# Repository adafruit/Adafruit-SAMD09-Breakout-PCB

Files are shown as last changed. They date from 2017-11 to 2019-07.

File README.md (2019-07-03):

## Adafruit SAMD09 Breakout PCB

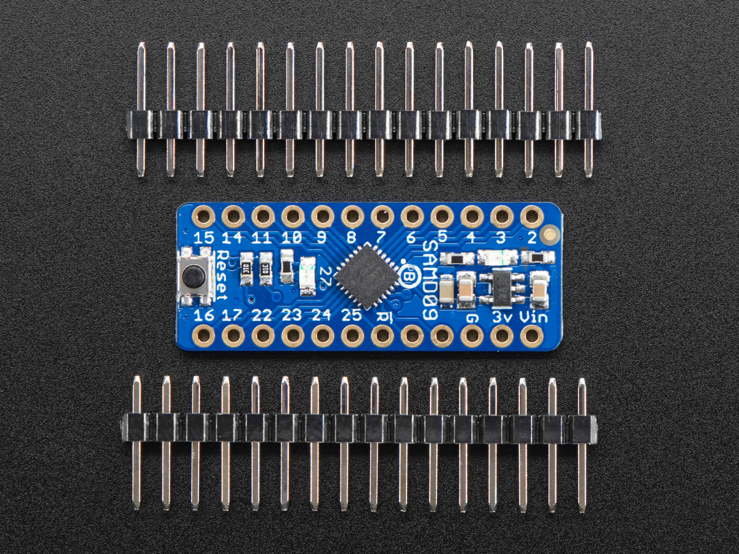
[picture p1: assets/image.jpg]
<a href="http://www.adafruit.com/products/3657"><br/>
Click here to purchase one from the Adafruit shop</a>

PCB files for the Adafruit SAMD09 microcontroller breakout

Format is EagleCAD schematic and board layout

For more details, check out the product page at
* https://www.adafruit.com/products/3657

### Description

Adafruit seesaw is a near-universal converter framework which allows you to add add and extend hardware support to any I2C-capable microcontroller or microcomputer. Instead of getting separate I2C GPIO expanders, ADCs, PWM drivers, etc, seesaw can be configured to give a wide range of capabilities.

For example, our ATSAMD09 breakout with seesaw gives you

* 3 x 12-bit ADC inputs
* 3 x 8-bit PWM outputs
* 7 x GPIO with selectable pullup or pulldown
* 1 x NeoPixel output (up to 340 pixels)
* 1 x EEPROM with 64 byte of NVM memory (handy for storing small access tokens or MAC addresses)
* 1 x Interrupt output that can be triggered by any of the accessories
* 2 x I2C address selection pins
* 1 x Activity LED

But you can reprogram and reconfigure the chip to have more or less of each peripheral - as long as it fits into the ATSAMD09D14's firmware! For example, there's also a UART converter but it isn't included in the default firmware.

The ATSAMD09 breakout is great for development of seesaw capabilities (we use it in-house for our design work) or you can use it as-is to give your Raspberry Pi or ESP8266 more hardware support! Each breakout comes with the assembled and tested board, as well as some header strips.

Please note: The boards do not come with a bootloader. If you want to do development on seesaw (e.g. changing the configuration) you'll need to pick up a J-Link and we recommend a SWD adapter breakout. 

### License

Adafruit invests time and resources providing this open source design, please support Adafruit and open-source hardware by purchasing products from [Adafruit](https://www.adafruit.com)!

Designed by Limor Fried/Ladyada for Adafruit Industries.

Creative Commons Attribution/Share-Alike, all text above must be included in any redistribution. See license.txt for additional details.

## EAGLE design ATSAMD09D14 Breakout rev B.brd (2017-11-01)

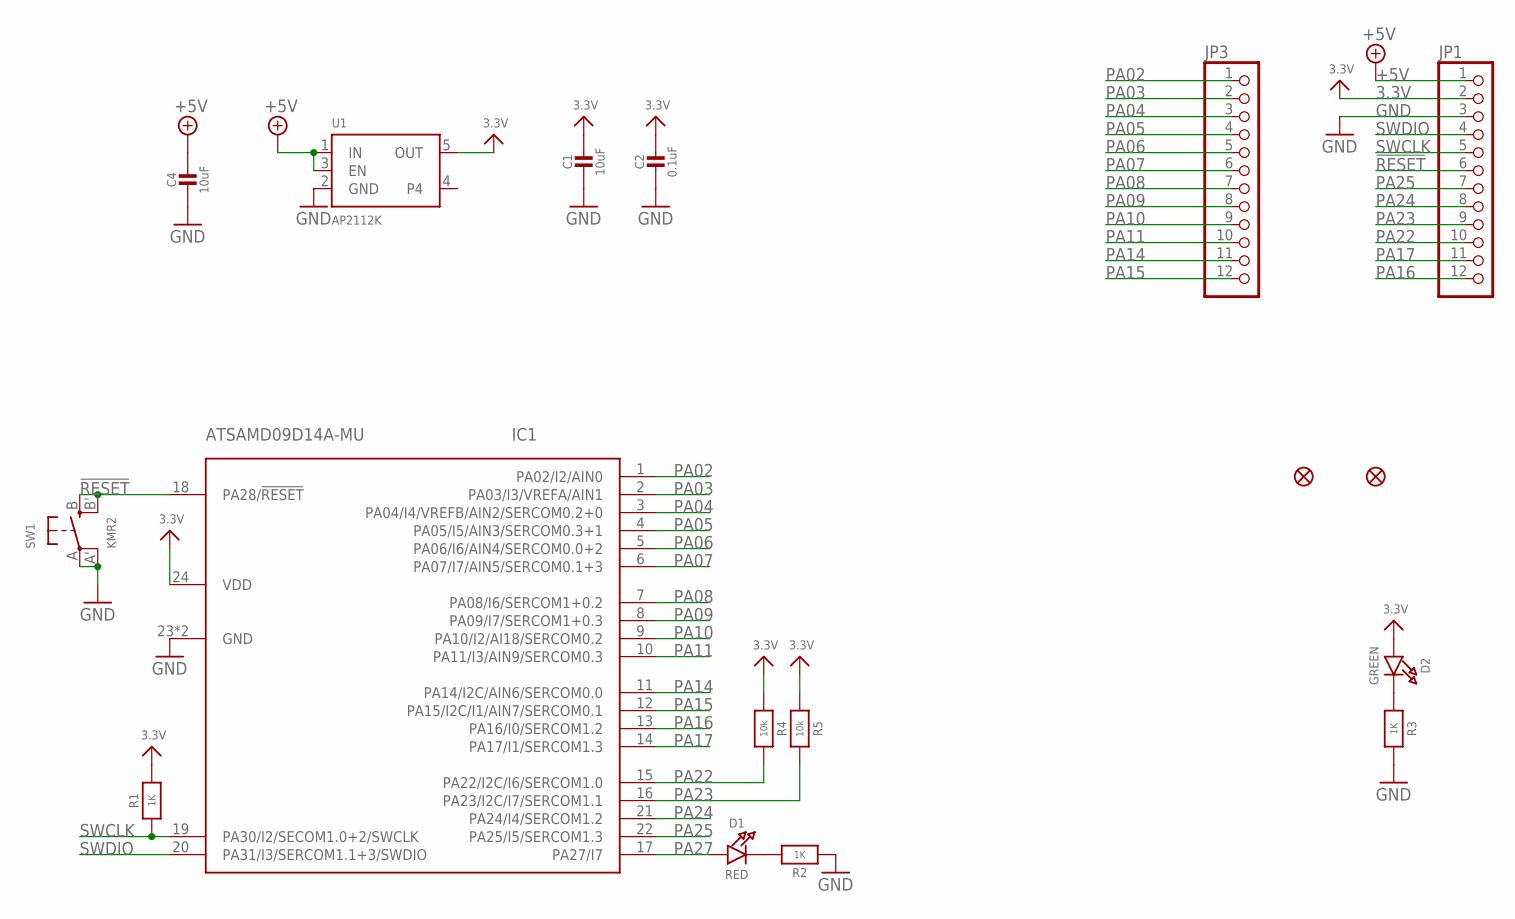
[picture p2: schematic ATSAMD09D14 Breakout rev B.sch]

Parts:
C1, C4: 10uF; 0805-NO
C2: 0.1uF; 0603-NO
D1: RED; CHIPLED_0805_NOOUTLINE
D2: GREEN; CHIPLED_0805_NOOUTLINE
FID1, FID2: FIDUCIAL""; FIDUCIAL_1MM
IC1: ATSAMD09D14A-MU; QFN24_4MM
JP1, JP3: HEADER-1X1276MIL; 1X12_ROUND_76MIL
R1, R2, R3: 1K; 0603-NO
R4, R5: 10k; 0603-NO
SW1: KMR2; BTN_KMR2_4.6X2.8
U1: AP2112K; SOT23-5

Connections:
3.3V: C1.1, C2.1, D2.A, IC1.24 (VDD), JP1.2, R1.2, R4.1, R5.1, U1.5 (OUT)
!RESET: IC1.18 (PA28/!RESET), JP1.6, SW1.B (S), SW1.B' (S1)
+5V: C4.1, JP1.1, U1.1 (IN), U1.3 (EN)
GND: C1.2, C2.2, C4.2, IC1.23 (GND), IC1.THERM (GND), JP1.3, R2.1, R3.2, SW1.A, SW1.A' (P1), U1.2 (GND)
unnamed: D1.C, R2.2
unnamed: D2.C, R3.1
PA02: IC1.1 (PA02/I2/AIN0), JP3.1
PA03: IC1.2 (PA03/I3/VREFA/AIN1), JP3.2
PA04: IC1.3 (PA04/I4/VREFB/AIN2/SERCOM0.2+0), JP3.3
PA05: IC1.4 (PA05/I5/AIN3/SERCOM0.3+1), JP3.4
PA06: IC1.5 (PA06/I6/AIN4/SERCOM0.0+2), JP3.5
PA07: IC1.6 (PA07/I7/AIN5/SERCOM0.1+3), JP3.6
PA08: IC1.7 (PA08/I6/SERCOM1+0.2), JP3.7
PA09: IC1.8 (PA09/I7/SERCOM1+0.3), JP3.8
PA10: IC1.9 (PA10/I2/AI18/SERCOM0.2), JP3.9
PA11: IC1.10 (PA11/I3/AIN9/SERCOM0.3), JP3.10
PA14: IC1.11 (PA14/I2C/AIN6/SERCOM0.0), JP3.11
PA15: IC1.12 (PA15/I2C/I1/AIN7/SERCOM0.1), JP3.12
PA16: IC1.13 (PA16/I0/SERCOM1.2), JP1.12
PA17: IC1.14 (PA17/I1/SERCOM1.3), JP1.11
PA22: IC1.15 (PA22/I2C/I6/SERCOM1.0), JP1.10, R4.2
PA23: IC1.16 (PA23/I2C/I7/SERCOM1.1), JP1.9, R5.2
PA24: IC1.21 (PA24/I4/SERCOM1.2), JP1.8
PA25: IC1.22 (PA25/I5/SERCOM1.3), JP1.7
PA27: D1.A, IC1.17 (PA27/I7)
SWCLK: IC1.19 (PA30/I2/SECOM1.0+2/SWCLK), JP1.5, R1.1
SWDIO: IC1.20 (PA31/I3/SERCOM1.1+3/SWDIO), JP1.4

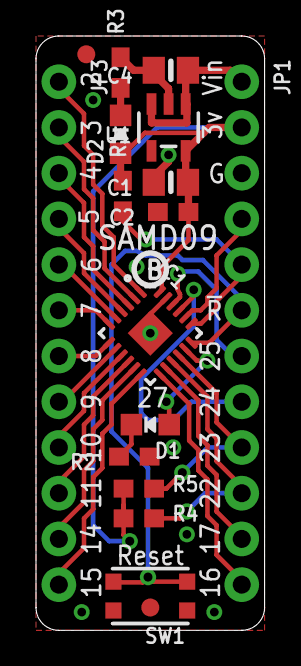
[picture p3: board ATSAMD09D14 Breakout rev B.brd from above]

Board: 2 copper layers, 12.7 x 33.0 mm, 19 parts (1 on the bottom side), 27 nets.

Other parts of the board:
U$7: SEESAW_LOGO
U$12: PCBFEAT-REV-040

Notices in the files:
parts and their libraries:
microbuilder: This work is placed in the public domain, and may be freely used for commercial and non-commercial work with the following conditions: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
